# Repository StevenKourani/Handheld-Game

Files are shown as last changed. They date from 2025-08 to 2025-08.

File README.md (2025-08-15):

# Handheld Game
A custom-built handheld console powered by an STM32 microcontroller, featuring a 2.8" TFT display, joystick/button controls, and modular game firmware.  
This repository contains both the **hardware design files** (KiCad) and **firmware source code**.

---
Handheld

## 🔧 Hardware Overview

- **MCU:** STM32F411RE (Nucleo board in development, custom PCB for production)  
- **Display:** ILI9341 2.8" TFT LCD (SPI)  
- **Controls:** Analog joystick + push buttons  
- **Audio:** Passive buzzer with PWM for sound effects  
- **Power:**
  - Li-ion battery with power management
  - **Buck-boost converter** allows the battery to be used both above and below 3.3V
  - USB-C charging option
  - Current switch for allowing fast charging of the battery
  - Power switch (on/off)
  - LED indicators for low battery and fully charged states  
- **PCB Design:** Created in KiCad 9, includes Gerbers, BOM, and KiCad project files.
- **Status:** Board was fabricated, and the power system was tested successfully.

---

## 💻 Firmware Overview

- Written in **C** using STM32 HAL drivers.
- Includes:
  - LCD graphics rendering
  - Joystick input via ADC
  - Button input with debouncing
  - Passive buzzer using PWM for sound effects
  - Game logic (Breakout, menu system, sound effects)
- Developed in **STM32CubeIDE**.
- Board is flashed using **Serial Wire Debug (SWD)**.
- Two additional onboard peripherals are available: **USART** and **I²C**.
- **Important:**  
  The code works, but you must update all pin numbers and peripheral configurations to match your own board.  
  In the first PCB revision, firmware flashing on the custom board was not possible due to a missing capacitor on the **VCAP** pin, preventing the CPU from running.  
  The current version in this repository has been updated to include this capacitor.

---

## 🎮 Game Details

- **Breakout** is implemented and functional but currently missing:
  - Pause function
  - Game Over function  
- Work is in progress to complete these features and to add more games, including **Snake**.

---

## 🚀 Getting Started

### 1. Hardware
- Open `Kicad/` in **KiCad 9.0**.
- Gerber and BOM files are available in `Gerbers/` and `Fabrication/` for PCB fabrication.

### 2. Firmware
- Open the `Inc/` and `Src/` folders in **STM32CubeIDE**.
- Connect your STM32 board (e.g., Nucleo-F411RE or your custom PCB).
- Compile and flash the firmware using **SWD**.

---

## 🤝 Contributing

This is my **first time designing and fabricating a PCB**.  
If anyone has improvements for the KiCad design or firmware, please:
- **Fork** this repository
- Make your changes
- Submit a **Pull Request** so the improvements can be reviewed and merged.

I would love to know if this updated version of the handheld works for you!

---

## 📜 License

This project is licensed under the **MIT License** (see `LICENSE` file).

---

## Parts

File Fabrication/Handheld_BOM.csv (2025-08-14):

Comment | Designator | Footprint | LCSC PN
C1,C2,C3,C4,C5,C10 | 100n | Capacitor_SMD:C_0402_1005Metric | C1525
C19 | 100n | Capacitor_SMD:C_0402_1005Metric | C105883
C17,C18 | 10u | Capacitor_SMD:C_0805_2012Metric | C694191
C6,C16,C20 | 10u | Capacitor_SMD:C_0603_1608Metric | C96446
C7 | 10n | Capacitor_SMD:C_0402_1005Metric | C15195
C8,C9 | 1u | Capacitor_SMD:C_0402_1005Metric | C52923
C11,C12 | 10p | Capacitor_SMD:C_0402_1005Metric | C32949
C13,C14,C15 | 4.7u | Capacitor_SMD:C_0603_1608Metric | C1705
C21,C22,C23 | 22u | Capacitor_SMD:C_0805_2012Metric | C258782
C24 | 2.2u | Capacitor_SMD:C_0402_1005Metric | C12530
D1 | ~ | LED_SMD:LED_0603_1608Metric | C12624
D2 | ~ | LED_SMD:LED_0603_1608Metric | C2286
D3 | ~ | LED_SMD:LED_0603_1608Metric | C2290
FB1 | 120R | Inductor_SMD:L_0603_1608Metric | C1002
J2 | USB_C_Receptacle_USB2.0_16P | Connector_USB:USB_C_Receptacle_GCT_USB4105-xx-A_16P_TopMnt_Horizontal | C5342196
L1 | XFL4020-152MEC | XFL4020-152MEC:IND_XFL4020-152MEC | C3033018
R1,R2,R3,R4,R5,R6,R9,R16 | 10k | Resistor_SMD:R_0402_1005Metric | C25744
R7,R8 | 5.1k | Resistor_SMD:R_0402_1005Metric | C25905
R10 | 2k | Resistor_SMD:R_0402_1005Metric | C4109
R11,R12 | 15k | Resistor_SMD:R_0402_1005Metric | C25756
R13,R14,R15 | 470 | Resistor_SMD:R_0402_1005Metric | C25117
R17 | 470k | Resistor_SMD:R_0402_1005Metric | C17709
R18 | 150k | Resistor_SMD:R_0402_1005Metric | C17470
R19 | 100k | Resistor_SMD:R_0402_1005Metric | C25741
R20,R21 | 1.5k | Resistor_SMD:R_0402_1005Metric | C25867
SW1,SW2,SW4 | SW_SPDT | Button_Switch_SMD:SW_SPDT_PCM12 | C221841
U1 | STM32F411RETx | Package_QFP:LQFP-64_10x10mm_P0.5mm | C94355
U3 | MCP73871-2CC | Package_DFN_QFN:QFN-20-1EP_4x4mm_P0.5mm_EP2.5x2.5mm | C5121473
U5 | TPS63070RNMR | TPS63070RNMR:VREG_TPS63070RNMR | C109322
Y1 | 16MHz | Crystal:Crystal_SMD_SeikoEpson_TSX3225-4Pin_3.2x2.5mm | C112972

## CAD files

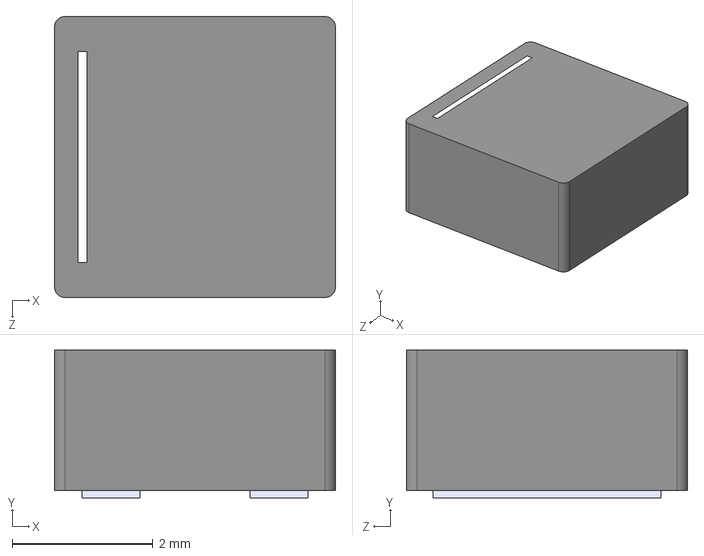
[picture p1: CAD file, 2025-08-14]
Kicad/XFL4020-152MEC.step
4.00 x 2.10 x 4.00 mm

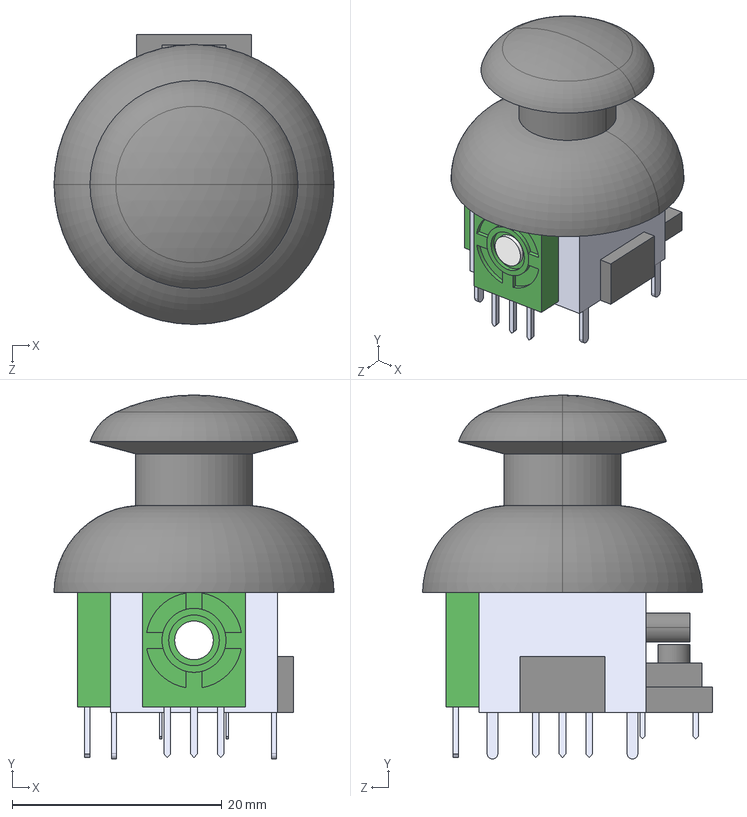
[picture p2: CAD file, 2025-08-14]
Kicad/COM-09032.step
26.7 x 34.7 x 27.6 mm

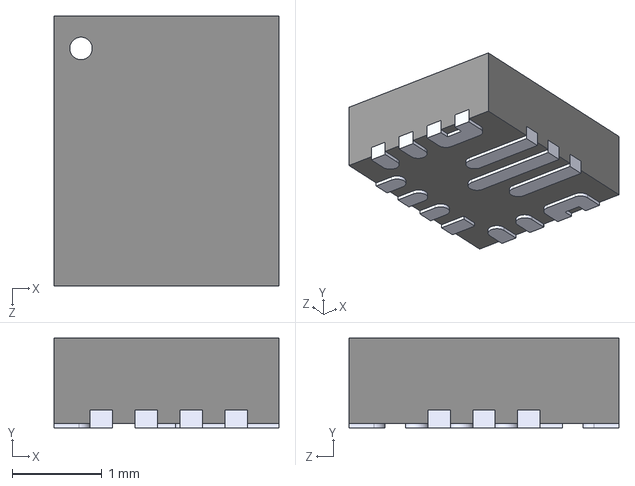
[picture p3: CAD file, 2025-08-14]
Kicad/TPS63070RNMR--3DModel-STEP-56544.STEP
2.50 x 1.00 x 3.00 mm

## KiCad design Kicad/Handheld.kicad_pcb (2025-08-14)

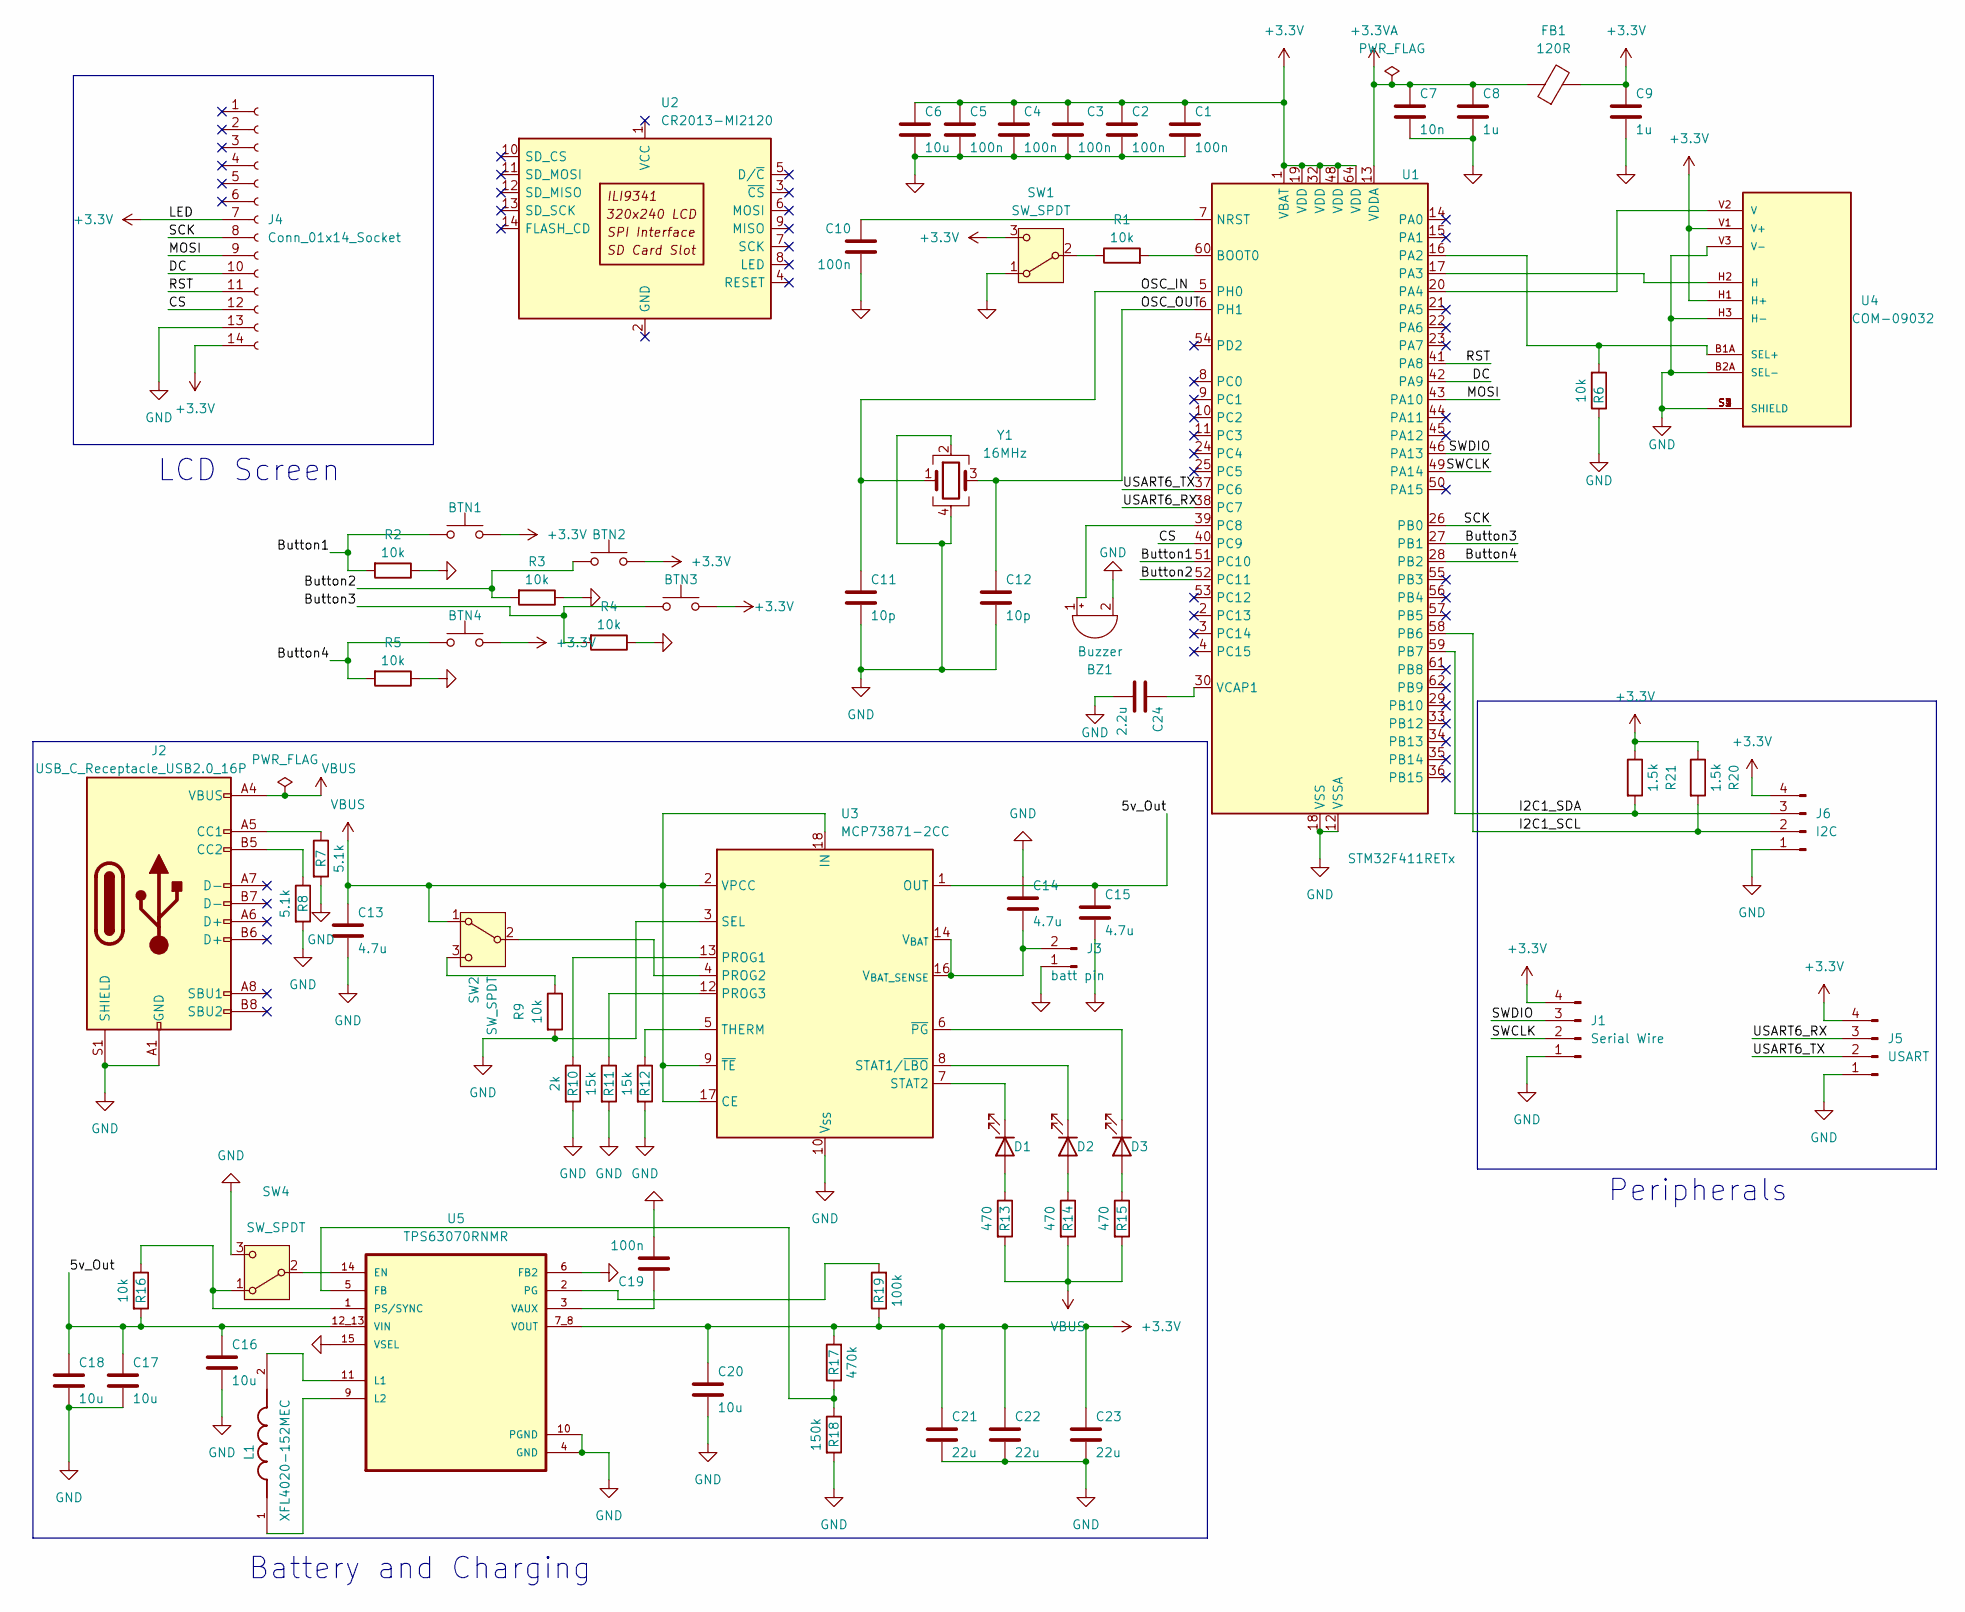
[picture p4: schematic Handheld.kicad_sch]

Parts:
BTN1, BTN2, BTN3, BTN4: SW_PUSH_6mm_H4.3mm
BZ1: Buzzer; Buzzer_TDK_PS1240P02BT_D12.2mm_H6.5mm
C1, C2, C3, C4, C5, C10: 100n; C_0402_1005Metric; LCSC C1525
C6, C16, C20: 10u; C_0603_1608Metric; LCSC C96446
C7: 10n; C_0402_1005Metric; LCSC C15195
C8, C9: 1u; C_0402_1005Metric; LCSC C52923
C11, C12: 10p; C_0402_1005Metric; LCSC C32949
C13, C14, C15: 4.7u; C_0603_1608Metric; LCSC C1705
C17, C18: 10u; C_0805_2012Metric; LCSC C694191
C19: 100n; C_0402_1005Metric; LCSC C105883
C21, C22, C23: 22u; C_0805_2012Metric; LCSC C258782
C24: 2.2u; C_0402_1005Metric; LCSC C12530
D1: LED_0603_1608Metric; LCSC C12624
D2: LED_0603_1608Metric; LCSC C2286
D3: LED_0603_1608Metric; LCSC C2290
FB1: 120R; L_0603_1608Metric; LCSC C1002
J1: Serial Wire; PinHeader_1x04_P2.54mm_Vertical
J2: USB_C_Receptacle_USB2.0_16P; USB_C_Receptacle_GCT_USB4105-xx-A_16P_TopMnt_Horizontal; LCSC C5342196
J3: batt pin; JST_PH_B2B-PH-K_1x02_P2.00mm_Vertical
J4: Conn_01x14_Socket; PinSocket_1x14_P2.54mm_Vertical
J5: USART; PinHeader_1x04_P2.54mm_Vertical
J6: I2C; PinHeader_1x04_P2.54mm_Vertical
L1: XFL4020-152MEC; IND_XFL4020-152MEC; PARTREV 11/02/18; LCSC C3033018
R1, R2, R3, R4, R5, R6, R9, R16: 10k; R_0402_1005Metric; LCSC C25744
R7, R8: 5.1k; R_0402_1005Metric; LCSC C25905
R10: 2k; R_0402_1005Metric; LCSC C4109
R11, R12: 15k; R_0402_1005Metric; LCSC C25756
R13, R14, R15: 470; R_0402_1005Metric; LCSC C25117
R17: 470k; R_0402_1005Metric; LCSC C17709
R18: 150k; R_0402_1005Metric; LCSC C17470
R19: 100k; R_0402_1005Metric; LCSC C25741
R20, R21: 1.5k; R_0402_1005Metric; LCSC C25867
SW1, SW4: SW_SPDT; SW_SPDT_PCM12; LCSC C221841
SW2: SW_SPDT; SW_SPDT_PCM12; LCSC C273395
U1: STM32F411RETx; LQFP-64_10x10mm_P0.5mm; LCSC C94355
U2: CR2013-MI2120
U3: MCP73871-2CC; QFN-20-1EP_4x4mm_P0.5mm_EP2.5x2.5mm; LCSC C5121473
U4: COM-09032; XDCR_COM-09032; PARTREV N/A
U5: TPS63070RNMR; VREG_TPS63070RNMR; LCSC C109322
Y1: 16MHz; Crystal_SMD_SeikoEpson_TSX3225-4Pin_3.2x2.5mm; LCSC C112972

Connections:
+3.3V: BTN1.1, BTN2.2, BTN3.2, BTN4.2, C1.1, C2.1, C3.1, C4.1, C5.1, C6.1, C9.1, C20.1, C21.1, C22.1, C23.1, FB1.2, J1.4, J4.7, J4.14, J5.4, J6.4, R17.2, R19.1, R20.1, R21.1, SW1.3 (C), U1.1 (VBAT), U1.19 (VDD), U1.32 (VDD), U1.48 (VDD), U1.64 (VDD), U4.H1 (H+), U4.V1 (V+), U5.7_8 (VOUT)
+3.3VA: C7.1, C8.1, FB1.1, U1.13 (VDDA)
/5v_Out: C15.1, C16.1, C17.1, C18.1, R16.2, U3.1 (OUT), U3.20 (OUT), U5.12_13 (VIN)
/Button1: BTN1.2, R2.2, U1.51 (PC10)
/Button2: BTN2.1, R3.2, U1.52 (PC11)
/Button3: BTN3.1, R4.2, U1.27 (PB1)
/Button4: BTN4.1, R5.2, U1.28 (PB2)
/CS: J4.12, U1.40 (PC9)
/DC: J4.10, U1.42 (PA9)
/I2C1_SCL: J6.2, R20.2, U1.58 (PB6)
/I2C1_SDA: J6.3, R21.2, U1.59 (PB7)
/MOSI: J4.9, U1.43 (PA10)
/OSC_IN: C11.1, U1.5 (PH0), Y1.1
/OSC_OUT: C12.1, U1.6 (PH1), Y1.3
/RST: J4.11, U1.41 (PA8)
/SCK: J4.8, U1.26 (PB0)
/SWCLK: J1.2, U1.49 (PA14)
/SWDIO: J1.3, U1.46 (PA13)
/USART6_RX: J5.3, U1.38 (PC7)
/USART6_TX: J5.2, U1.37 (PC6)
GND: BZ1.2 (-), C1.2, C2.2, C3.2, C4.2, C5.2, C6.2, C7.2, C8.2, C9.2, C10.2, C11.2, C12.2, C13.2, C14.1, C15.2, C16.2, C17.2, C18.2, C19.2, C20.2, C21.2, C22.2, C23.2, C24.2, J1.1, J2.A1 (GND), J2.A12 (GND), J2.B1 (GND), J2.B12 (GND), J2.S1 (SHIELD), J3.1, J4.13, J5.1, J6.1, R2.1, R3.1, R4.1, R5.1, R6.1, R7.2, R8.2, R9.2, R10.2, R11.2, R12.2, R18.2, SW1.1 (A), SW4.3 (C), U1.12 (VSSA), U1.18 (VSS), U1.31 (VSS), U1.47 (VSS), U1.63 (VSS), U3.3 (SEL), U3.10 (V_{SS}), U3.11 (V_{SS}), U3.21 (V_{SS}), U4.B2A (SEL-), U4.H3 (H-), U4.S1 (SHIELD), U4.S2 (SHIELD), U4.S3 (SHIELD), U4.S4 (SHIELD), U4.V3 (V-), U5.4 (GND), U5.6 (FB2), U5.10 (PGND), U5.15 (VSEL), Y1.2, Y1.4
unnamed: BZ1.1 (+), U1.39 (PC8)
unnamed: D1.2 (A), R13.1
unnamed: D1.1 (K), U3.7 (STAT2)
unnamed: D2.2 (A), R14.1
unnamed: D2.1 (K), U3.8 (STAT1/~LBO)
unnamed: D3.2 (A), R15.1
unnamed: D3.1 (K), U3.6 (~PG)
unnamed: J2.A5 (CC1), R7.1
unnamed: J2.B5 (CC2), R8.1
unnamed: C14.2, J3.2, U3.14 (V_{BAT}), U3.15 (V_{BAT}), U3.16 (V_{BAT_SENSE})
unnamed: R1.1, SW1.2 (B)
unnamed: SW2.2 (B), U3.4 (PROG2)
unnamed: R9.1, SW2.3 (C)
unnamed: R16.1, SW4.1 (A), U5.1 (PS/SYNC)
unnamed: SW4.2 (B), U5.14 (EN)
unnamed: R1.2, U1.60 (BOOT0)
unnamed: C10.1, U1.7 (NRST)
unnamed: R6.2, U1.16 (PA2), U4.B1A (SEL+)
unnamed: U1.17 (PA3), U4.H2 (H)
unnamed: U1.20 (PA4), U4.V2 (V)
unnamed: C24.1, U1.30 (VCAP1)
unnamed: R10.1, U3.13 (PROG1)
unnamed: R11.1, U3.12 (PROG3)
unnamed: R12.1, U3.5 (THERM)
unnamed: R17.1, R18.1, U5.5 (FB)
unnamed: L1.2, U5.11 (L1)
unnamed: L1.1, U5.9 (L2)
unnamed: R19.2, U5.2 (PG)
unnamed: C19.1, U5.3 (VAUX)
VBUS: C13.1, J2.A4 (VBUS), J2.A9 (VBUS), J2.B4 (VBUS), J2.B9 (VBUS), R13.2, R14.2, R15.2, SW2.1 (A), U3.2 (VPCC), U3.9 (~TE), U3.17 (CE), U3.18 (IN), U3.19 (IN)

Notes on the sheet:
Battery and Charging
Peripherals
LCD Screen

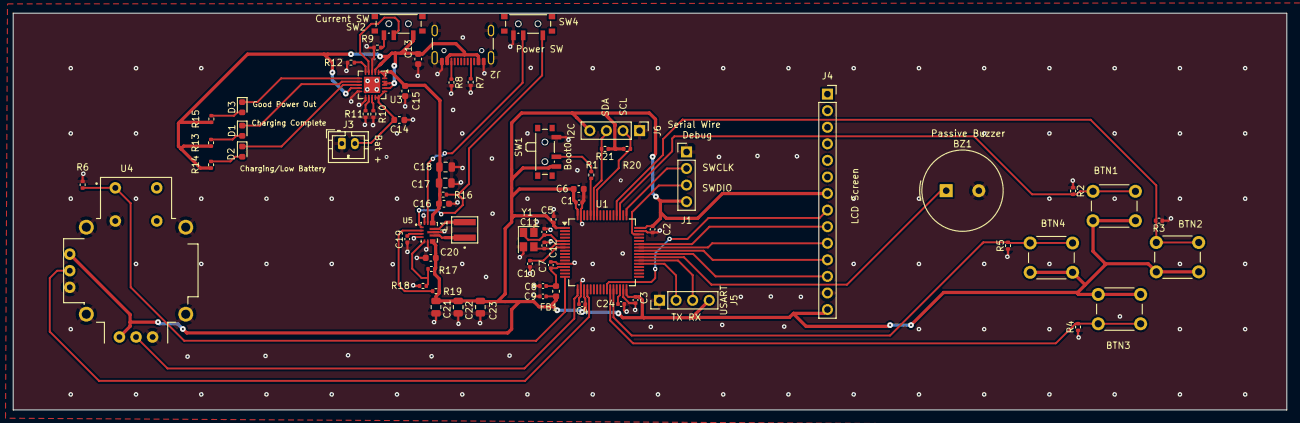
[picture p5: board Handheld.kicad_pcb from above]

Board: 2 copper layers, 195.2 x 60.8 mm, 69 parts (0 on the bottom side), 51 nets.

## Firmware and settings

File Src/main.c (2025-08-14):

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
/* Includes ------------------------------------------------------------------*/
#include "main.h"

/* USER CODE BEGIN Includes */
#include <stdio.h>
#include <string.h>
#include <stdarg.h>
#include "ili9341.h"
#include "ili9341_touch.h"
#include "fonts.h"
#include "GUI_Icons.h"
#include "Game_screen.h"
#include "Breakout.h"
#include "Sound_Screen.h"



/* USER CODE END Includes */

ADC_HandleTypeDef hadc1;
DMA_HandleTypeDef hdma_adc1;

SPI_HandleTypeDef hspi3;
DMA_HandleTypeDef hdma_spi3_tx;

TIM_HandleTypeDef htim2;

UART_HandleTypeDef huart2;

/* USER CODE BEGIN PV */
AppState appState = STATE_MENU;

GameState gameState = GAME_MENU;

SoundState soundState = SOUND_MENU;

int buzzerState = LOW;

DebounceButton btnA = {GPIOB, GPIO_PIN_5, LOW, LOW, 0};
DebounceButton btnB   = {GPIOA, GPIO_PIN_10, LOW, LOW, 0};
unsigned long debounceDelay = 50;


uint16_t xValue;
uint16_t yValue;
uint32_t readValue[2];
uint8_t button_state;
char buffer[50];


/* USER CODE END PV */

void SystemClock_Config(void);
static void MX_GPIO_Init(void);
static void MX_DMA_Init(void);
static void MX_USART2_UART_Init(void);
static void MX_TIM2_Init(void);
static void MX_ADC1_Init(void);
static void MX_SPI3_Init(void);
/* USER CODE BEGIN 0 */

void debounceButton(DebounceButton* btn, unsigned long debounceDelay) {
    int reading = HAL_GPIO_ReadPin(btn->port, btn->pin);

    if (reading != btn->lastState) {
        btn->lastDebounceTime = HAL_GetTick();
    }

    if ((HAL_GetTick() - btn->lastDebounceTime) > debounceDelay) {
        if (reading != btn->state) {
            btn->state = reading;
        }
    }

    btn->lastState = reading;
}




	void init() {
		ILI9341_Unselect();
		ILI9341_Init();
	}


/* USER CODE END 0 */

/**
  * @brief  The application entry point.
  * @retval int
  */
int main(void)
{

  /* MCU Configuration--------------------------------------------------------*/

  /* Reset of all peripherals, Initializes the Flash interface and the Systick. */
  HAL_Init();

  /* Configure the system clock */
  SystemClock_Config();

  /* Initialize all configured peripherals */
  MX_GPIO_Init();
  MX_DMA_Init();
  MX_USART2_UART_Init();
  MX_TIM2_Init();
  MX_ADC1_Init();
  MX_SPI3_Init();
  /* USER CODE BEGIN 2 */

  __HAL_TIM_SET_COMPARE(&htim2,TIM_CHANNEL_2, 0);
  HAL_TIM_PWM_Start(&htim2, TIM_CHANNEL_2);

  HAL_ADC_Start_DMA(&hadc1, (uint32_t*)readValue, 2);


  /* USER CODE END 2 */

  /* Infinite loop */
  /* USER CODE BEGIN WHILE */
  init();
  screen();
  icons();
  while (1)
  {
    /* USER CODE END WHILE */

    /* USER CODE BEGIN 3 */

	  switch(appState) {
		 case STATE_MENU:
			 icon_select();
			 break;
		 case STATE_GAME_SELECT:
			 switch(gameState) {
				 case GAME_MENU:
					 game_select();
					 break;
				 case STATE_GAME_1:
					 updatePaddle();
					 updateBall();
					 detectCollision();
					 updateScoreboard();
					 game1_buttons();
					 break;
				 case STATE_GAME_2:
					 break;
				 }
			 break;
		 case STATE_SOUND:
			  switch(soundState) {
				 case SOUND_MENU:
					 sound_select();
					 break;
				 case STATE_SOUND_1:
					 break;
				 case STATE_SOUND_2:
					 break;
				 case STATE_SOUND_3:
					 break;
				 }
			 break;
		 case STATE_SETTINGS:
			 break;
		 }


	  debounceButton(&btnA, debounceDelay);
	  debounceButton(&btnB, debounceDelay);


  }
  /* USER CODE END 3 */
}

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


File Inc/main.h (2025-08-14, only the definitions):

#define B1_Pin GPIO_PIN_13
#define B1_GPIO_Port GPIOC
#define USART_TX_Pin GPIO_PIN_2
#define USART_TX_GPIO_Port GPIOA
#define USART_RX_Pin GPIO_PIN_3
#define USART_RX_GPIO_Port GPIOA
#define LD2_Pin GPIO_PIN_5
#define LD2_GPIO_Port GPIOA
#define TMS_Pin GPIO_PIN_13
#define TMS_GPIO_Port GPIOA
#define TCK_Pin GPIO_PIN_14
#define TCK_GPIO_Port GPIOA
#define HIGH GPIO_PIN_SET
#define LOW GPIO_PIN_RESET

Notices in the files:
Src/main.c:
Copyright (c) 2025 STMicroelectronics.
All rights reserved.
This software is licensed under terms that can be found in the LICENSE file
